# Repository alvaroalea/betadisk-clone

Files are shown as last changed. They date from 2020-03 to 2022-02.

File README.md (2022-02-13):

# The Beta 128K Interface Disk for ZX Spectrum
the schematic and PCB for this interfaz, make in KICAD
Including gerber files to direct order, the PCB is just 15x10cm.

# THIS IS WORK IN PROGRESS.ACTUALY THIS INTERFACE DO NOT WORK!!!!! BE AWARE
## NOT FOR USE, THIS IS ONLY A MOCKUP, WORK IN PROGRESS

(C) 2018 Alvaro Alea Fernandez.



This work is licensed under a Creative Commons Attribution-NonCommercial-ShareAlike 4.0 International License.

http://creativecommons.org/licenses/by-nc-sa/4.0/

BOM is probably not acurrate, gerbers have names wrong.

GAL code is not checked

Even this interface provide a back conector for other interfaces, it do not provide a good IORQ signals, so can be incompatible with other interfaces that original interface is working good.

This board hide the serial port on +2.

The Advantege of this interfaz over the original are:

- 4 Banks of ROM, so you can swap between diferent versiones of TR-Dos. selectable by dip-switches
  (TR-DOS 5.03 and 5.04T with fixed, TR-DOS 6.04 & velesoft 5.03 with monitor.

- Posibility of use crossed and plain floppy cable, and invert Drive 1 and Drive 2, very usefull if you have a Gotek and a real floppy.

- Jumper for swap D0 & D7 (because some roms are distributed with this bits swapeed)

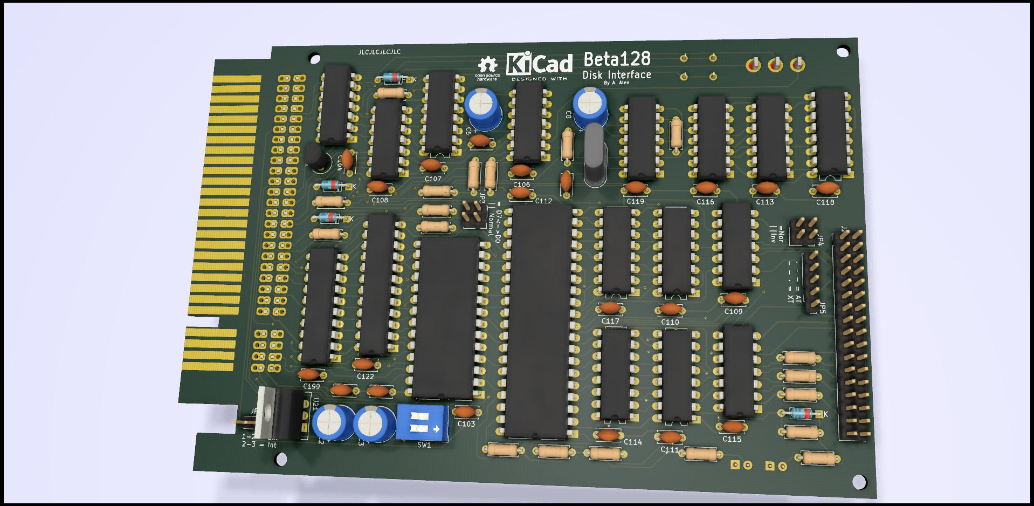
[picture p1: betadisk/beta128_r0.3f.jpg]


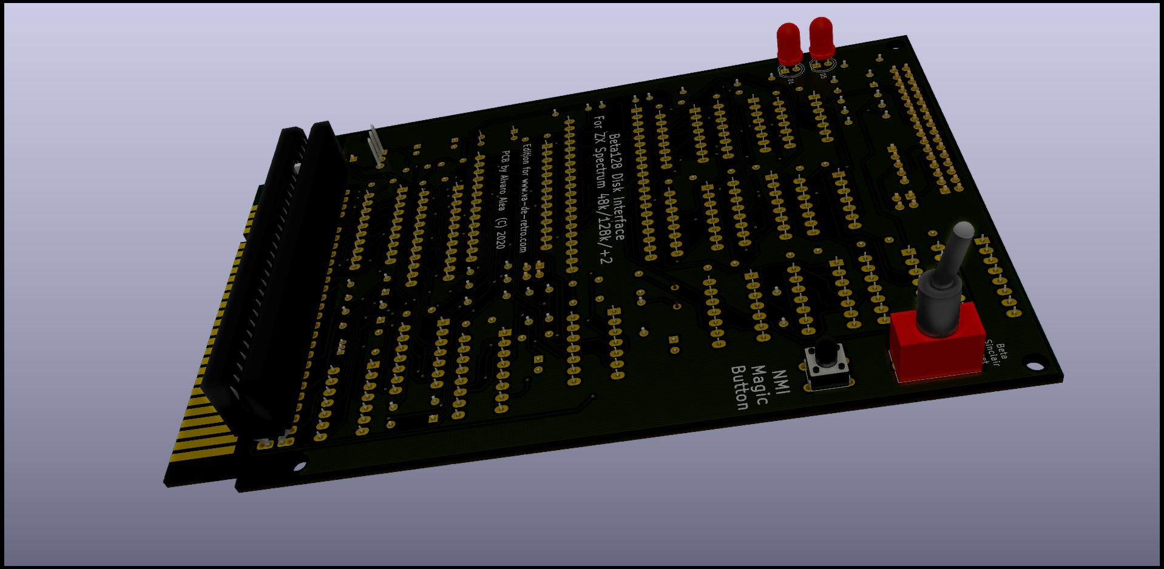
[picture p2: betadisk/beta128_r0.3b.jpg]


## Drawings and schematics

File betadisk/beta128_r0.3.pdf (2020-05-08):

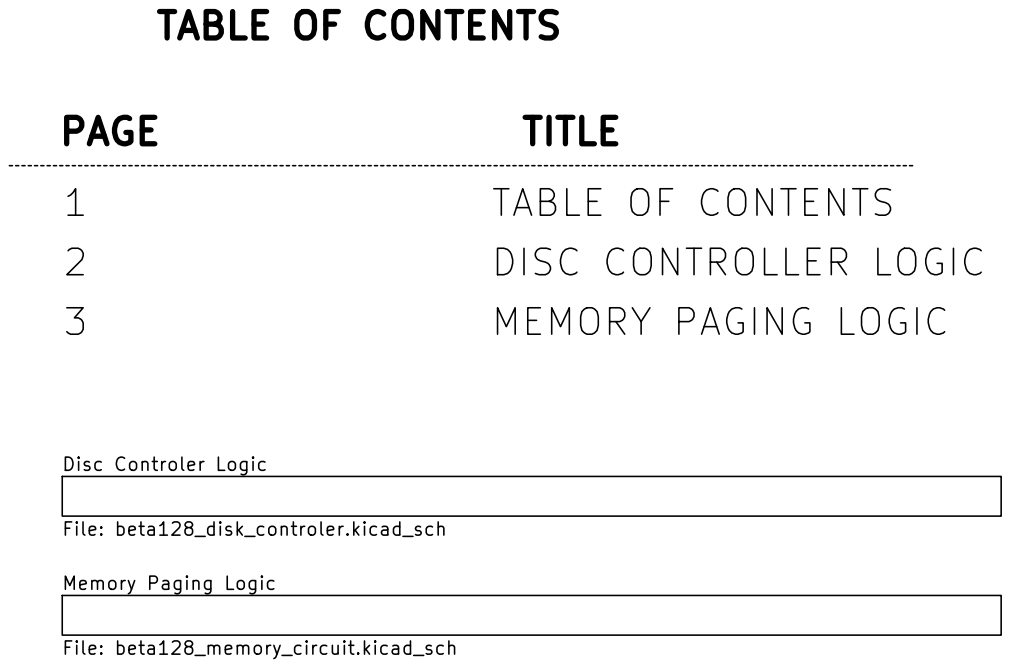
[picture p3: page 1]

Disc Controler Logic File: beta128_disk_controler.kicad_sch Memory Paging Logic

File: beta128_r0.3.kicad_sch Sheet: / Alvaro Alea Fdz. Based on Rev 5 (Beta 128) Under Licence GPL3

Id: 1/3 Title: Beta Disk Interface

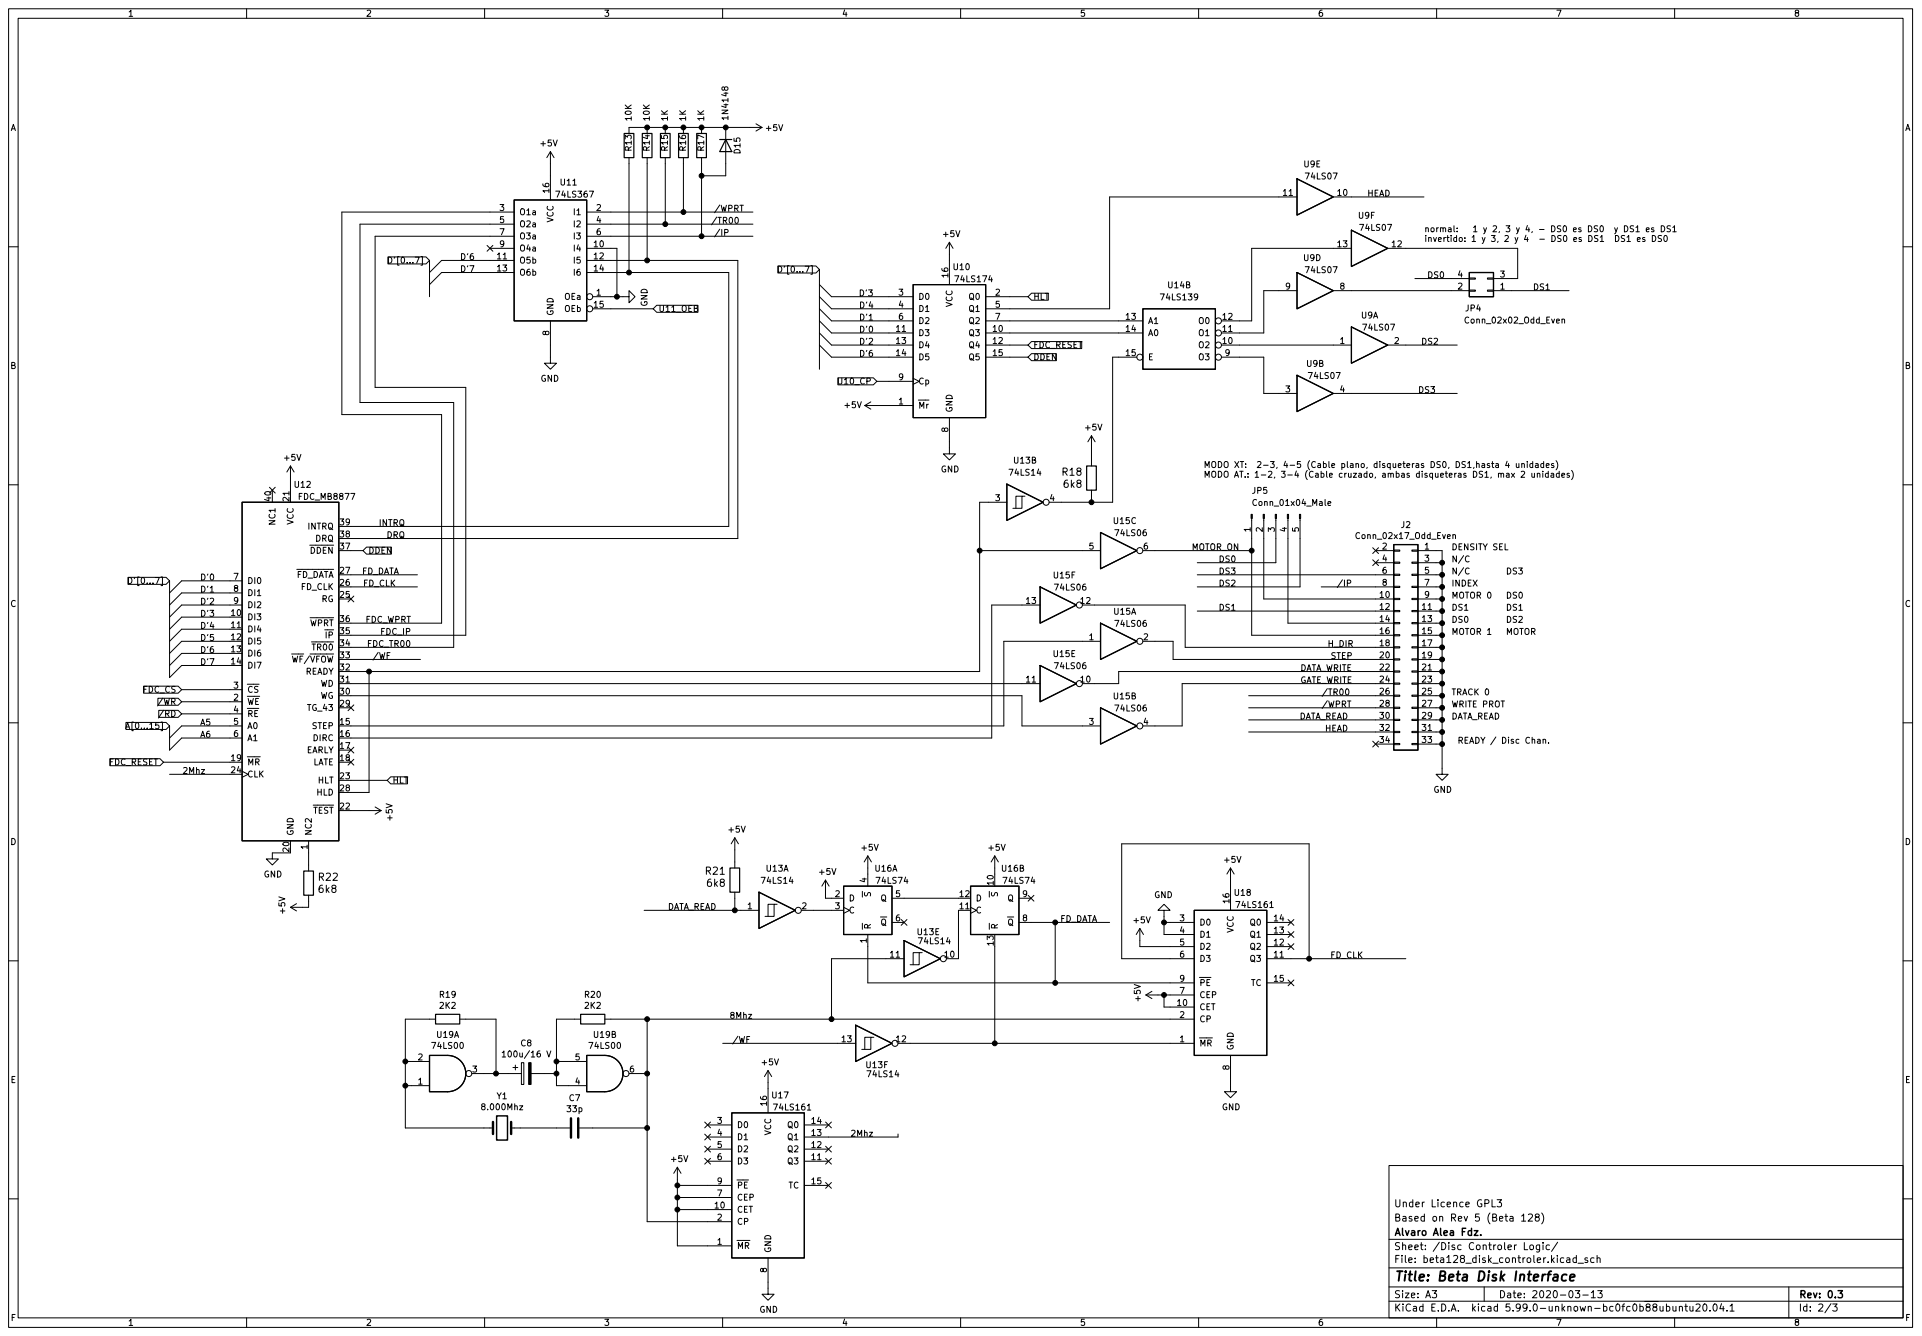
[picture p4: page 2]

invertido: 1 y 3, 2 y 4 - DS0 es DS1 DS1 es DS0 DENSITY SEL TRACK 0 WRITE PROT DATA_READ

24 | 23
26 | 25

File: beta128_disk_controler.kicad_sch
Id: 2/3 Title: Beta Disk Interface

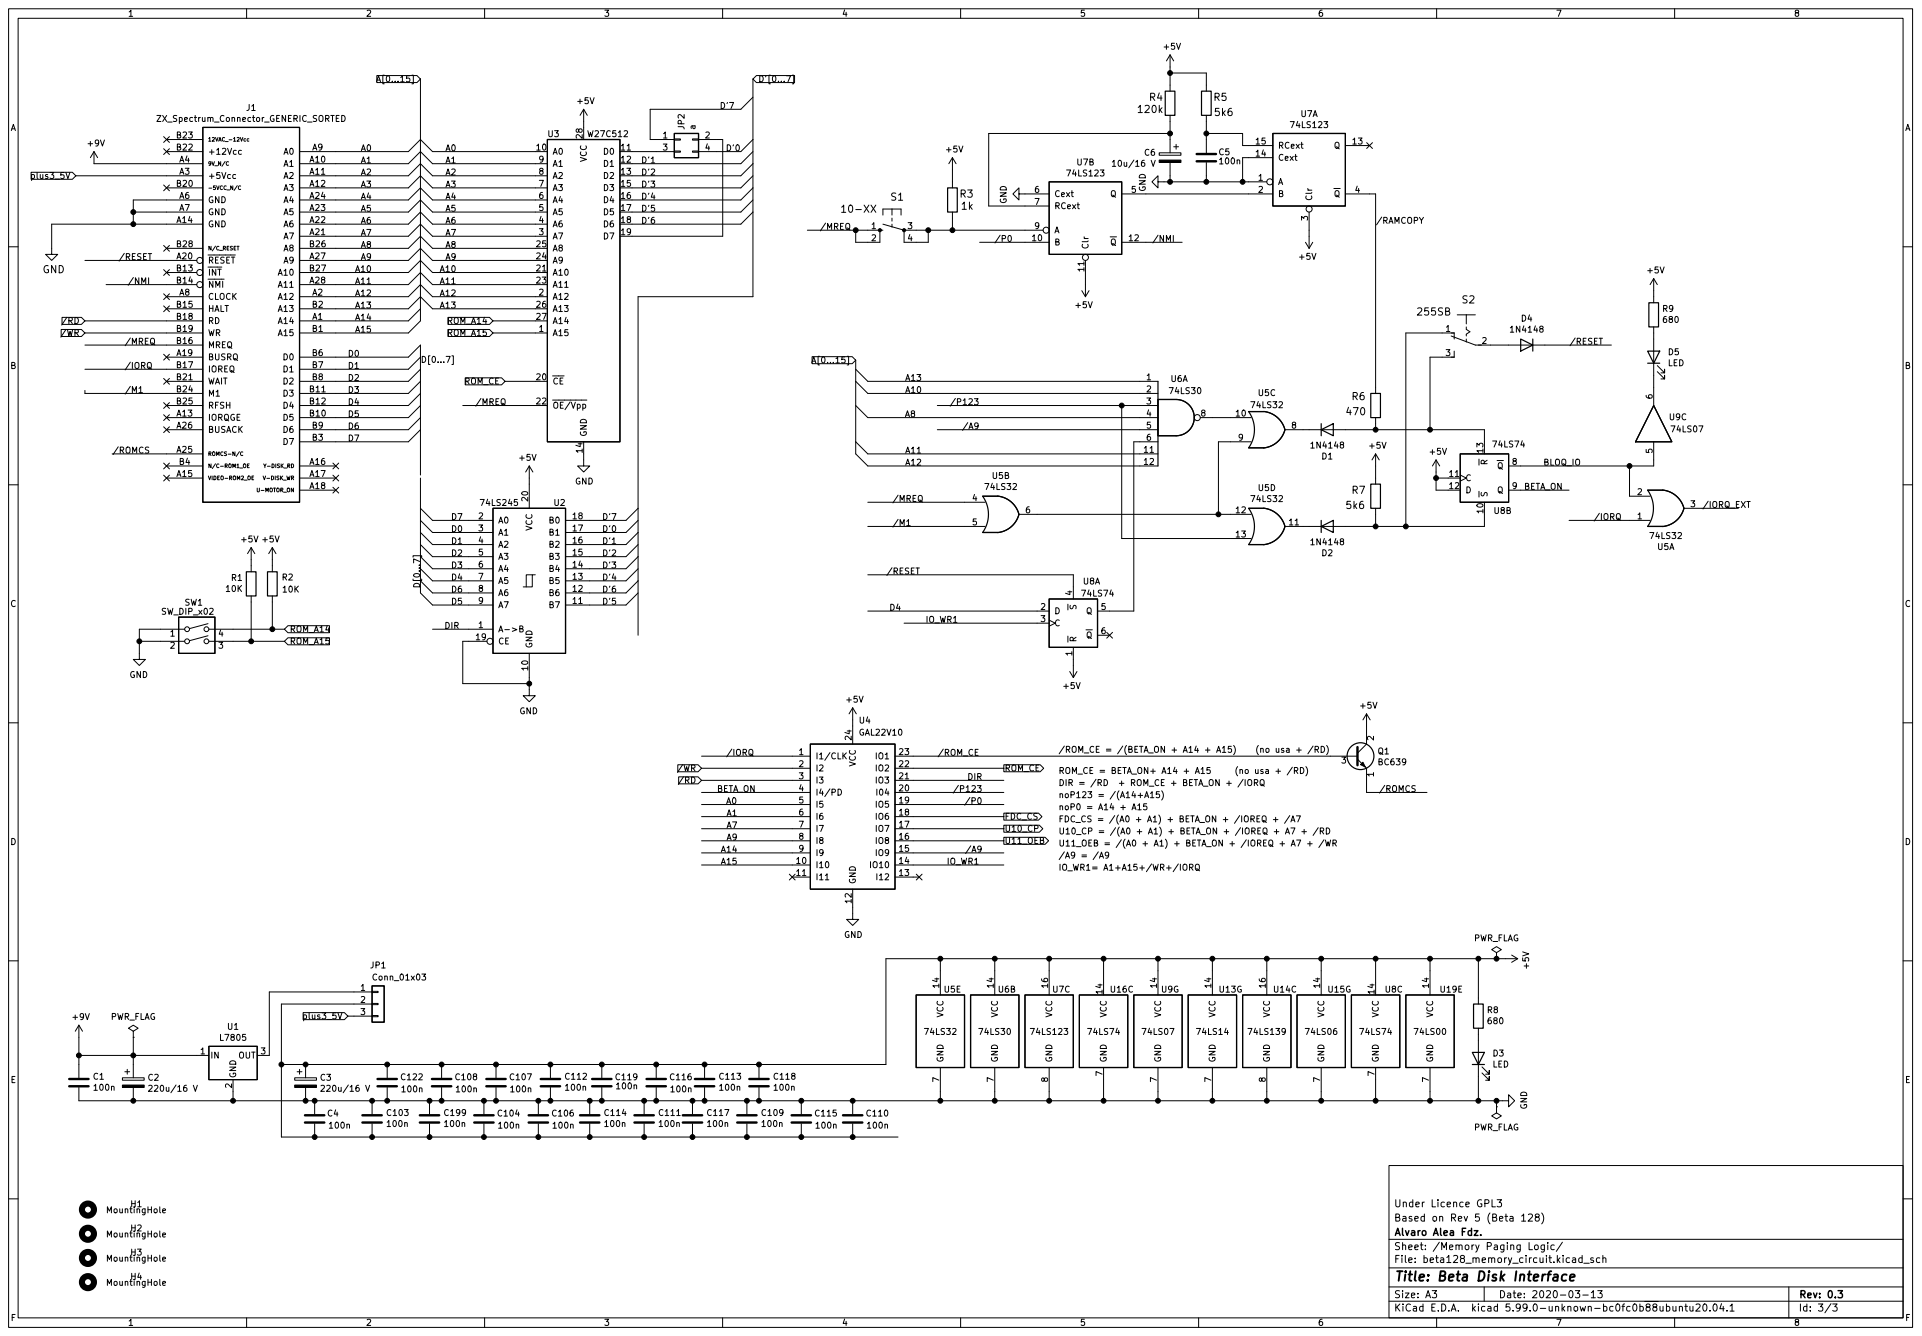
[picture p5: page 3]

Sheet: /Memory Paging Logic/ Alvaro Alea Fdz. Based on Rev 5 (Beta 128) Under Licence GPL3

File: beta128_memory_circuit.kicad_sch
Id: 3/3 Title: Beta Disk Interface

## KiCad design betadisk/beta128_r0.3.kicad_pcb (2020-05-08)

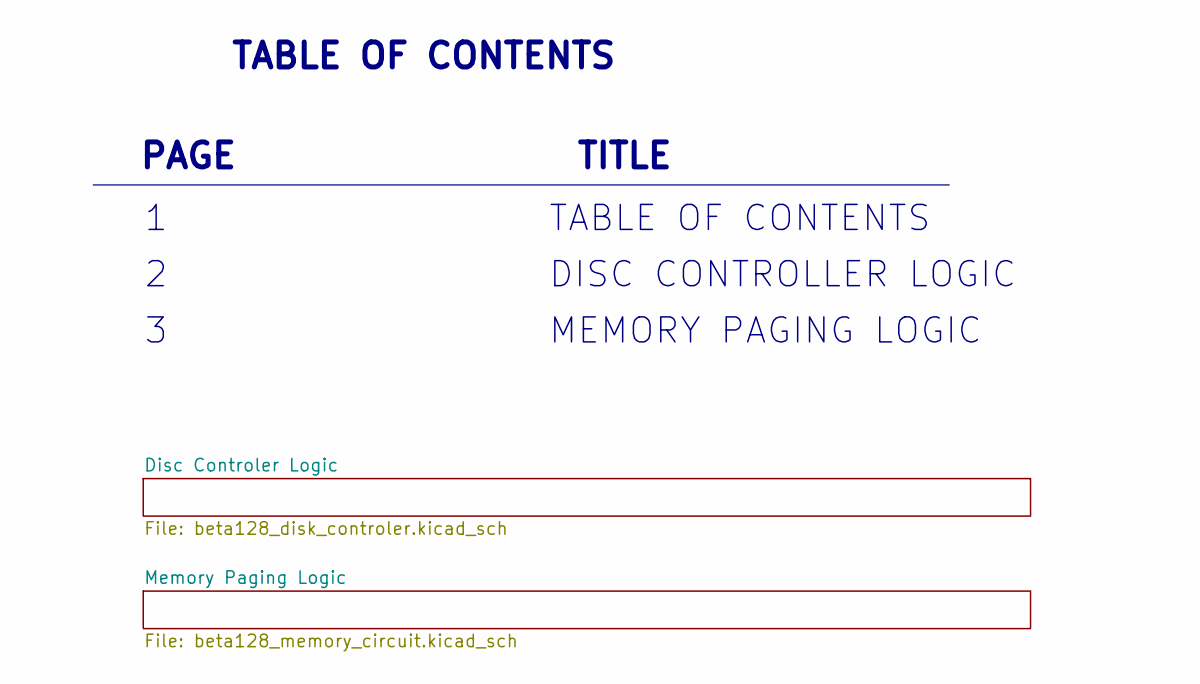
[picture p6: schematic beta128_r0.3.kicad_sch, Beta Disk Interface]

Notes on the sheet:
1 TABLE OF CONTENTS
2 DISC CONTROLLER LOGIC
3 MEMORY PAGING LOGIC
TABLE OF CONTENTS
PAGE TITLE

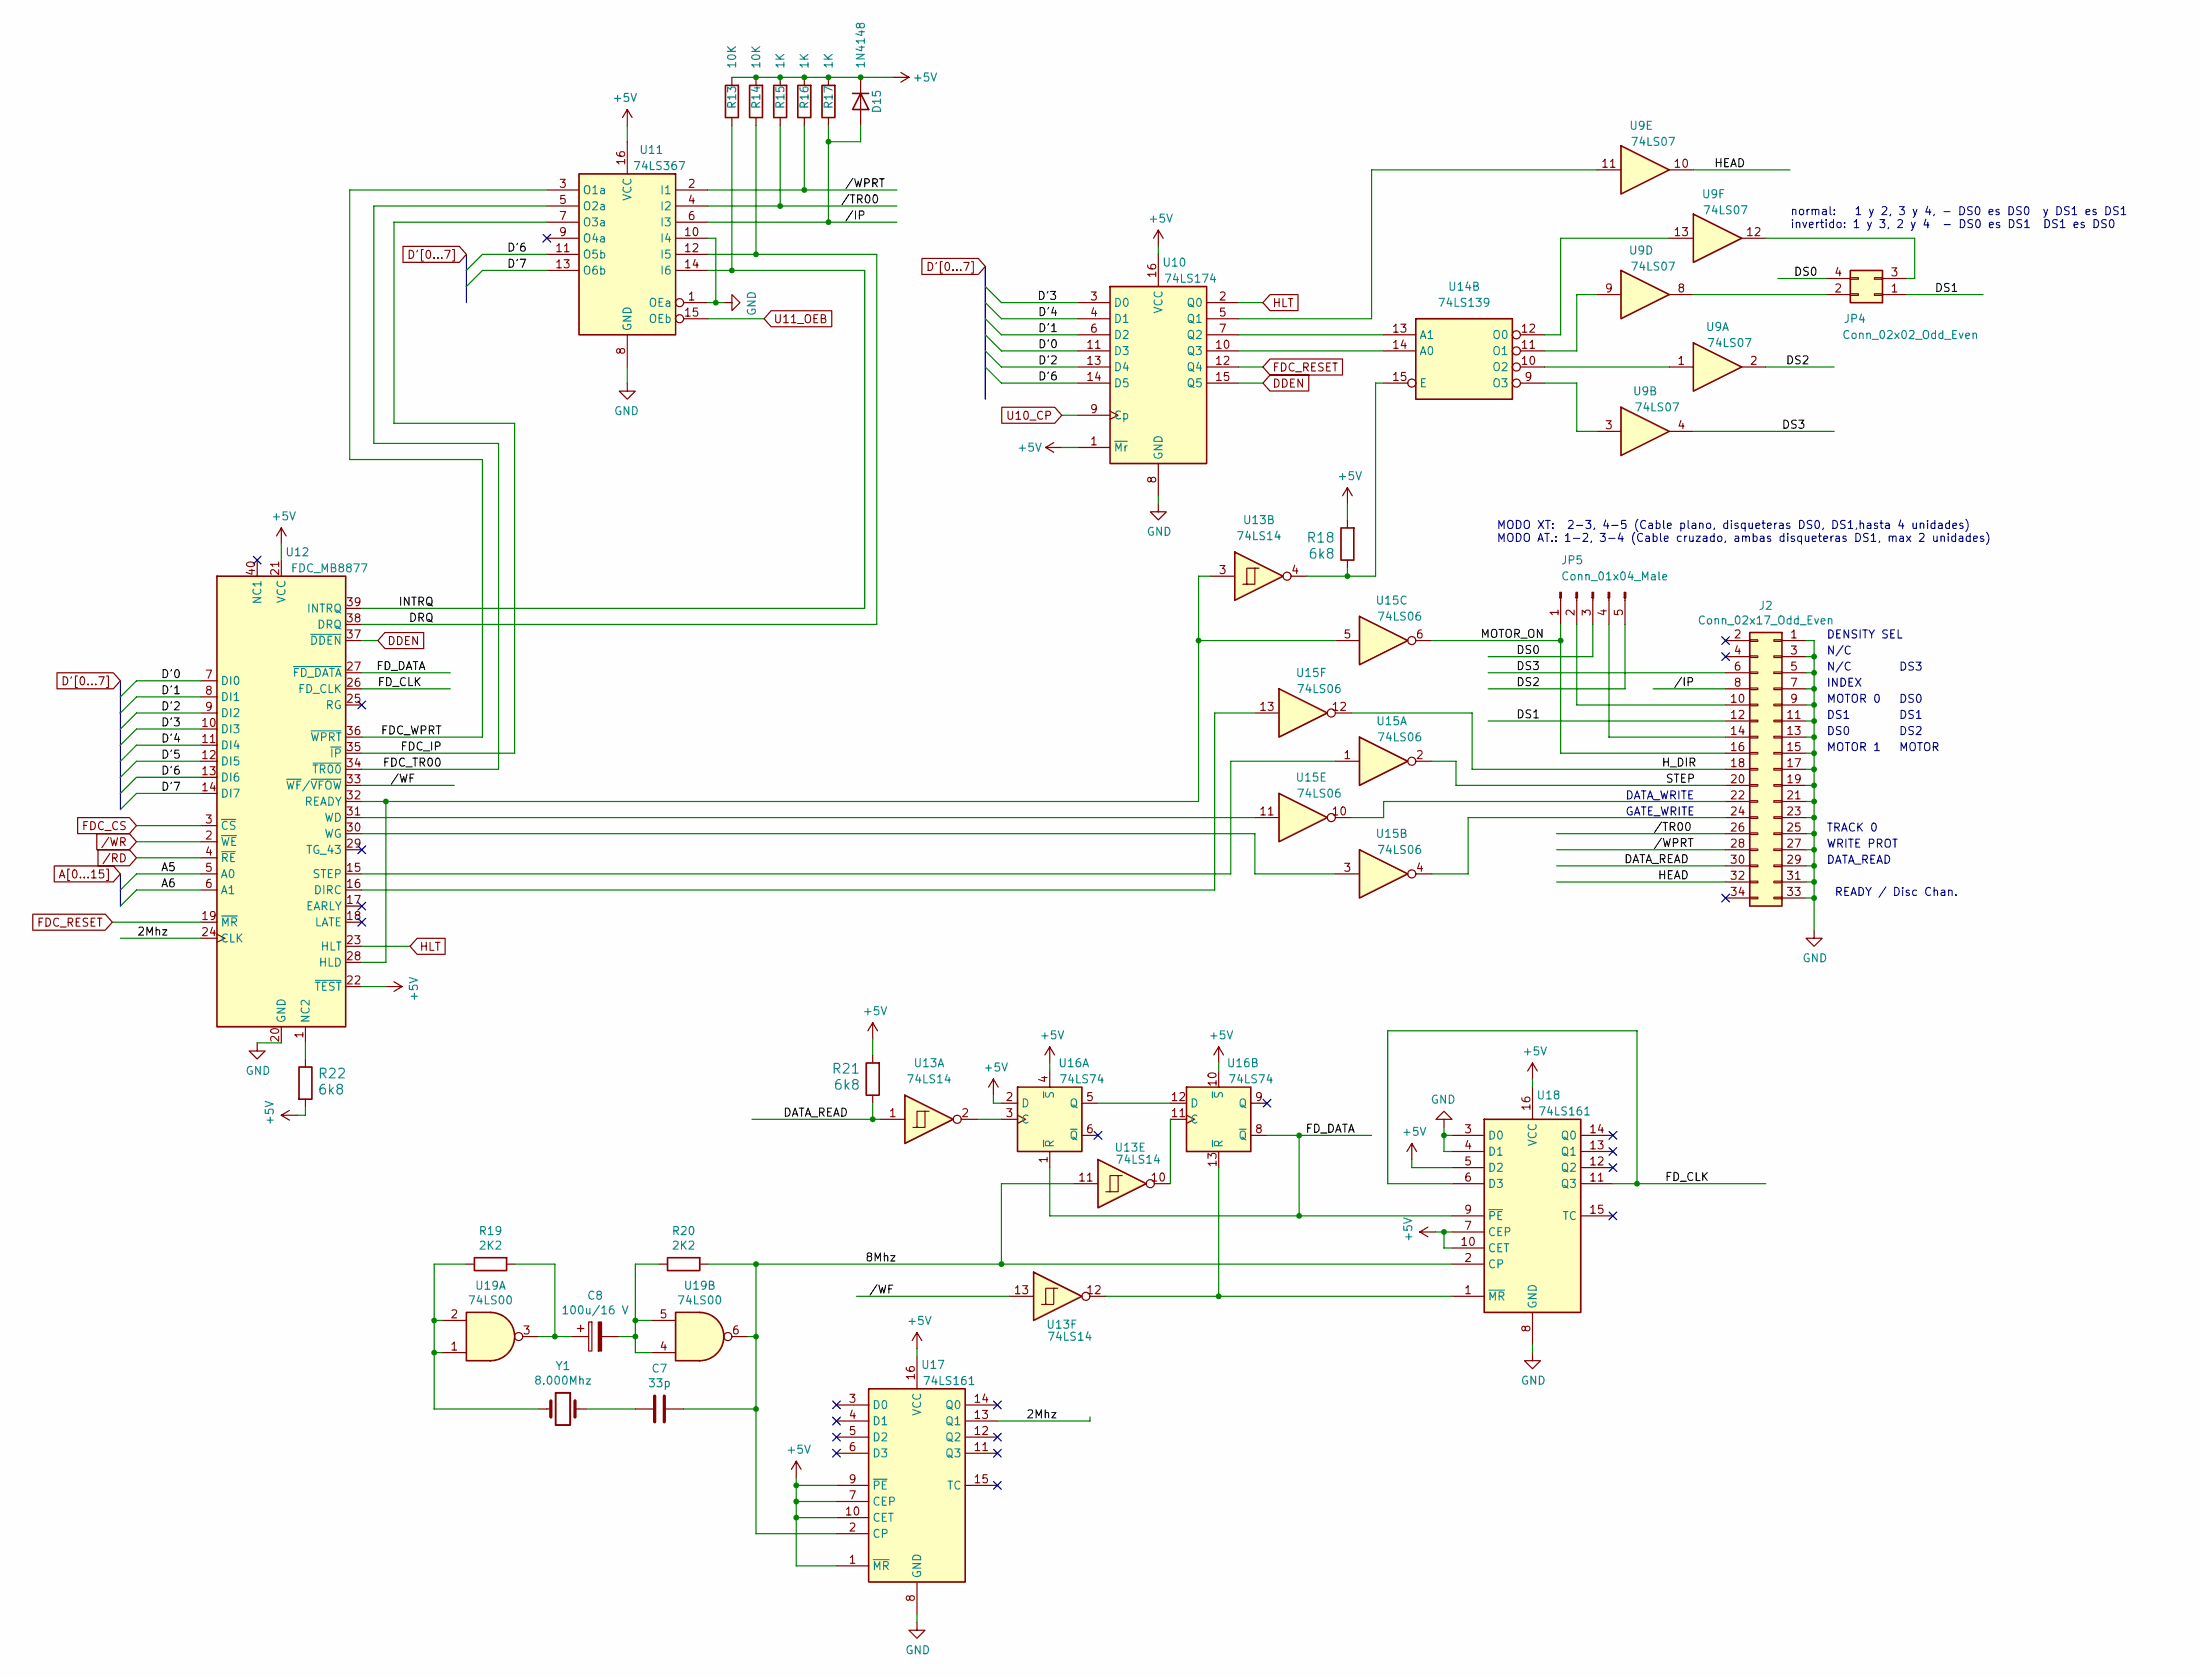
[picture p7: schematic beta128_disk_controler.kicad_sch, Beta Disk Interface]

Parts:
C7: 33p; C_Disc_D5.0mm_W2.5mm_P5.00mm
C8: 100u/16 V; CP_Radial_D7.5mm_P2.50mm
D15: 1N4148; D_DO-35_SOD27_P7.62mm_Horizontal
J2: Conn_02x17_Odd_Even; PinHeader_2x17_P2.54mm_Vertical
JP4: Conn_02x02_Odd_Even; PinHeader_2x02_P2.54mm_Vertical
JP5: Conn_01x04_Male; PinHeader_1x05_P2.54mm_Vertical
R13, R14: 10K; R_Axial_DIN0207_L6.3mm_D2.5mm_P7.62mm_Horizontal
R15, R16, R17: 1K; R_Axial_DIN0207_L6.3mm_D2.5mm_P7.62mm_Horizontal
R18, R21, R22: 6k8; R_Axial_DIN0207_L6.3mm_D2.5mm_P7.62mm_Horizontal
R19, R20: 2K2; R_Axial_DIN0207_L6.3mm_D2.5mm_P7.62mm_Horizontal
U9: 74LS07; DIP-14_W7.62mm_LongPads
U10: 74LS174; DIP-16_W7.62mm_LongPads
U11: 74LS367; DIP-16_W7.62mm_LongPads
U12: FDC_MB8877; DIP-40_W15.24mm_LongPads
U13: 74LS14; DIP-14_W7.62mm_LongPads
U14: 74LS139; DIP-16_W7.62mm_LongPads
U15: 74LS06; DIP-14_W7.62mm_LongPads
U16: 74LS74; DIP-14_W7.62mm_LongPads
U17, U18: 74LS161; DIP-16_W7.62mm_LongPads
U19: 74LS00; DIP-14_W7.62mm_LongPads
Y1: 8.000Mhz; Crystal_HC18-U_Vertical

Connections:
+5V: D15.1 (K), R13.2, R14.2, R15.2, R16.2, R17.2, R18.2, R21.2, R22.2, U10.1 (~Mr), U10.16 (VCC), U11.16 (VCC), U12.21 (VCC), U12.22 (~TEST), U16.2 (D), U16.4 (~S), U16.10 (~S), U17.1 (~MR), U17.7 (CEP), U17.9 (~PE), U17.10 (CET), U17.16 (VCC), U18.5 (D2), U18.7 (CEP), U18.10 (CET), U18.16 (VCC); also elsewhere on the board
/Disc Controler Logic/2Mhz: U12.24 (CLK), U17.13 (Q1)
/Disc Controler Logic/8Mhz: C7.2, R20.2, U13.11, U17.2 (CP), U18.2 (CP), U19.6
/Disc Controler Logic//IP: D15.2 (A), J2.8, R17.1, U11.6 (I3)
/Disc Controler Logic//TR00: J2.26, R15.1, U11.4 (I2)
/Disc Controler Logic//WF: U12.33 (~WF~/~VFOW), U13.13
/Disc Controler Logic//WPRT: J2.28, R16.1, U11.2 (I1)
/Disc Controler Logic/DATA_READ: J2.30, R21.1, U13.1
/Disc Controler Logic/DRQ: R14.1, U11.12 (I5), U12.38 (DRQ)
/Disc Controler Logic/DS0: JP4.4, JP5.3
/Disc Controler Logic/DS1: J2.12, JP4.1
/Disc Controler Logic/DS2: JP5.5, U9.2
/Disc Controler Logic/DS3: J2.6, U9.4
/Disc Controler Logic/FDC_IP: U11.7 (O3a), U12.35 (~IP)
/Disc Controler Logic/FDC_TR00: U11.5 (O2a), U12.34 (~TR00)
/Disc Controler Logic/FDC_WPRT: U11.3 (O1a), U12.36 (~WPRT)
/Disc Controler Logic/FD_CLK: U12.26 (FD_CLK), U18.6 (D3), U18.11 (Q3)
/Disc Controler Logic/FD_DATA: U12.27 (~FD_DATA), U16.1 (~R), U16.8 (~Q), U18.9 (~PE)
/Disc Controler Logic/HEAD: J2.32, U9.10
/Disc Controler Logic/H_DIR: J2.18, U15.12
/Disc Controler Logic/INTRQ: R13.1, U11.14 (I6), U12.39 (INTRQ)
/Disc Controler Logic/MOTOR_ON: J2.16, JP5.1, U15.6
/Disc Controler Logic/STEP: J2.20, U15.2
/RD: U12.4 (~RE); also elsewhere on the board
/WR: U12.2 (~WE); also elsewhere on the board
A5: U12.5 (A0); also elsewhere on the board
A6: U12.6 (A1); also elsewhere on the board
D'0: U10.11 (D3), U12.7 (DI0); also elsewhere on the board
D'1: U10.6 (D2), U12.8 (DI1); also elsewhere on the board
D'2: U10.13 (D4), U12.9 (DI2); also elsewhere on the board
D'3: U10.3 (D0), U12.10 (DI3); also elsewhere on the board
D'4: U10.4 (D1), U12.11 (DI4); also elsewhere on the board
D'5: U12.12 (DI5); also elsewhere on the board
D'6: U10.14 (D5), U11.11 (O5b), U12.13 (DI6); also elsewhere on the board
D'7: U11.13 (O6b), U12.14 (DI7); also elsewhere on the board
DDEN: U10.15 (Q5), U12.37 (~DDEN)
FDC_CS: U12.3 (~CS); also elsewhere on the board
FDC_RESET: U10.12 (Q4), U12.19 (~MR)
GND: J2.1, J2.3, J2.5, J2.7, J2.9, J2.11, J2.13, J2.15, J2.17, J2.19, J2.21, J2.23, J2.25, J2.27, J2.29, J2.31, J2.33, U10.8 (GND), U11.1 (OEa), U11.8 (GND), U11.10 (I4), U12.20 (GND), U17.8 (GND), U18.3 (D0), U18.4 (D1), U18.8 (GND); also elsewhere on the board
HLT: U10.2 (Q0), U12.23 (HLT)
unnamed: C7.1, Y1.1
unnamed: C8.1, R19.2, U19.3
unnamed: C8.2, R20.1, U19.4, U19.5
unnamed: J2.10, JP5.2
unnamed: J2.14, JP5.4
unnamed: J2.22, U15.10
unnamed: J2.24, U15.4
unnamed: JP4.2, U9.8
unnamed: JP4.3, U9.12
unnamed: R18.1, U13.4, U14.15 (E)
unnamed: R19.1, U19.1, U19.2, Y1.2
unnamed: R22.1, U12.1 (NC2)
unnamed: U9.11, U10.5 (Q1)
unnamed: U10.7 (Q2), U14.13 (A1)
unnamed: U10.10 (Q3), U14.14 (A0)
unnamed: U12.15 (STEP), U15.1
unnamed: U12.16 (DIRC), U15.13
unnamed: U12.28 (HLD), U12.32 (READY), U13.3, U15.5
unnamed: U12.30 (WG), U15.3
unnamed: U12.31 (WD), U15.11
unnamed: U13.2, U16.3 (C)
unnamed: U13.10, U16.11 (C)
unnamed: U13.12, U16.13 (~R), U18.1 (~MR)
unnamed: U9.3, U14.9 (O3)
unnamed: U9.1, U14.10 (O2)
unnamed: U9.9, U14.11 (O1)
unnamed: U9.13, U14.12 (O0)
unnamed: U16.5 (Q), U16.12 (D)
U10_CP: U10.9 (Cp); also elsewhere on the board
U11_OEB: U11.15 (OEb); also elsewhere on the board

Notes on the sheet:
MODO XT: 2-3, 4-5 (Cable plano, disqueteras DS0, DS1,hasta 4 unidades) MODO AT.: 1-2, 3-4 (Cable cruzado, ambas disqueteras DS1, max 2 unidades)
DATA_WRITE
GATE_WRITE
normal: 1 y 2, 3 y 4, - DS0 es DS0 y DS1 es DS1 invertido: 1 y 3, 2 y 4 - DS0 es DS1 DS1 es DS0
DENSITY SEL
N/C
INDEX
MOTOR 0
DS1
DS0
MOTOR 1
TRACK 0
WRITE PROT
DATA_READ
READY / Disc Chan.
DS3
DS0
DS2
MOTOR

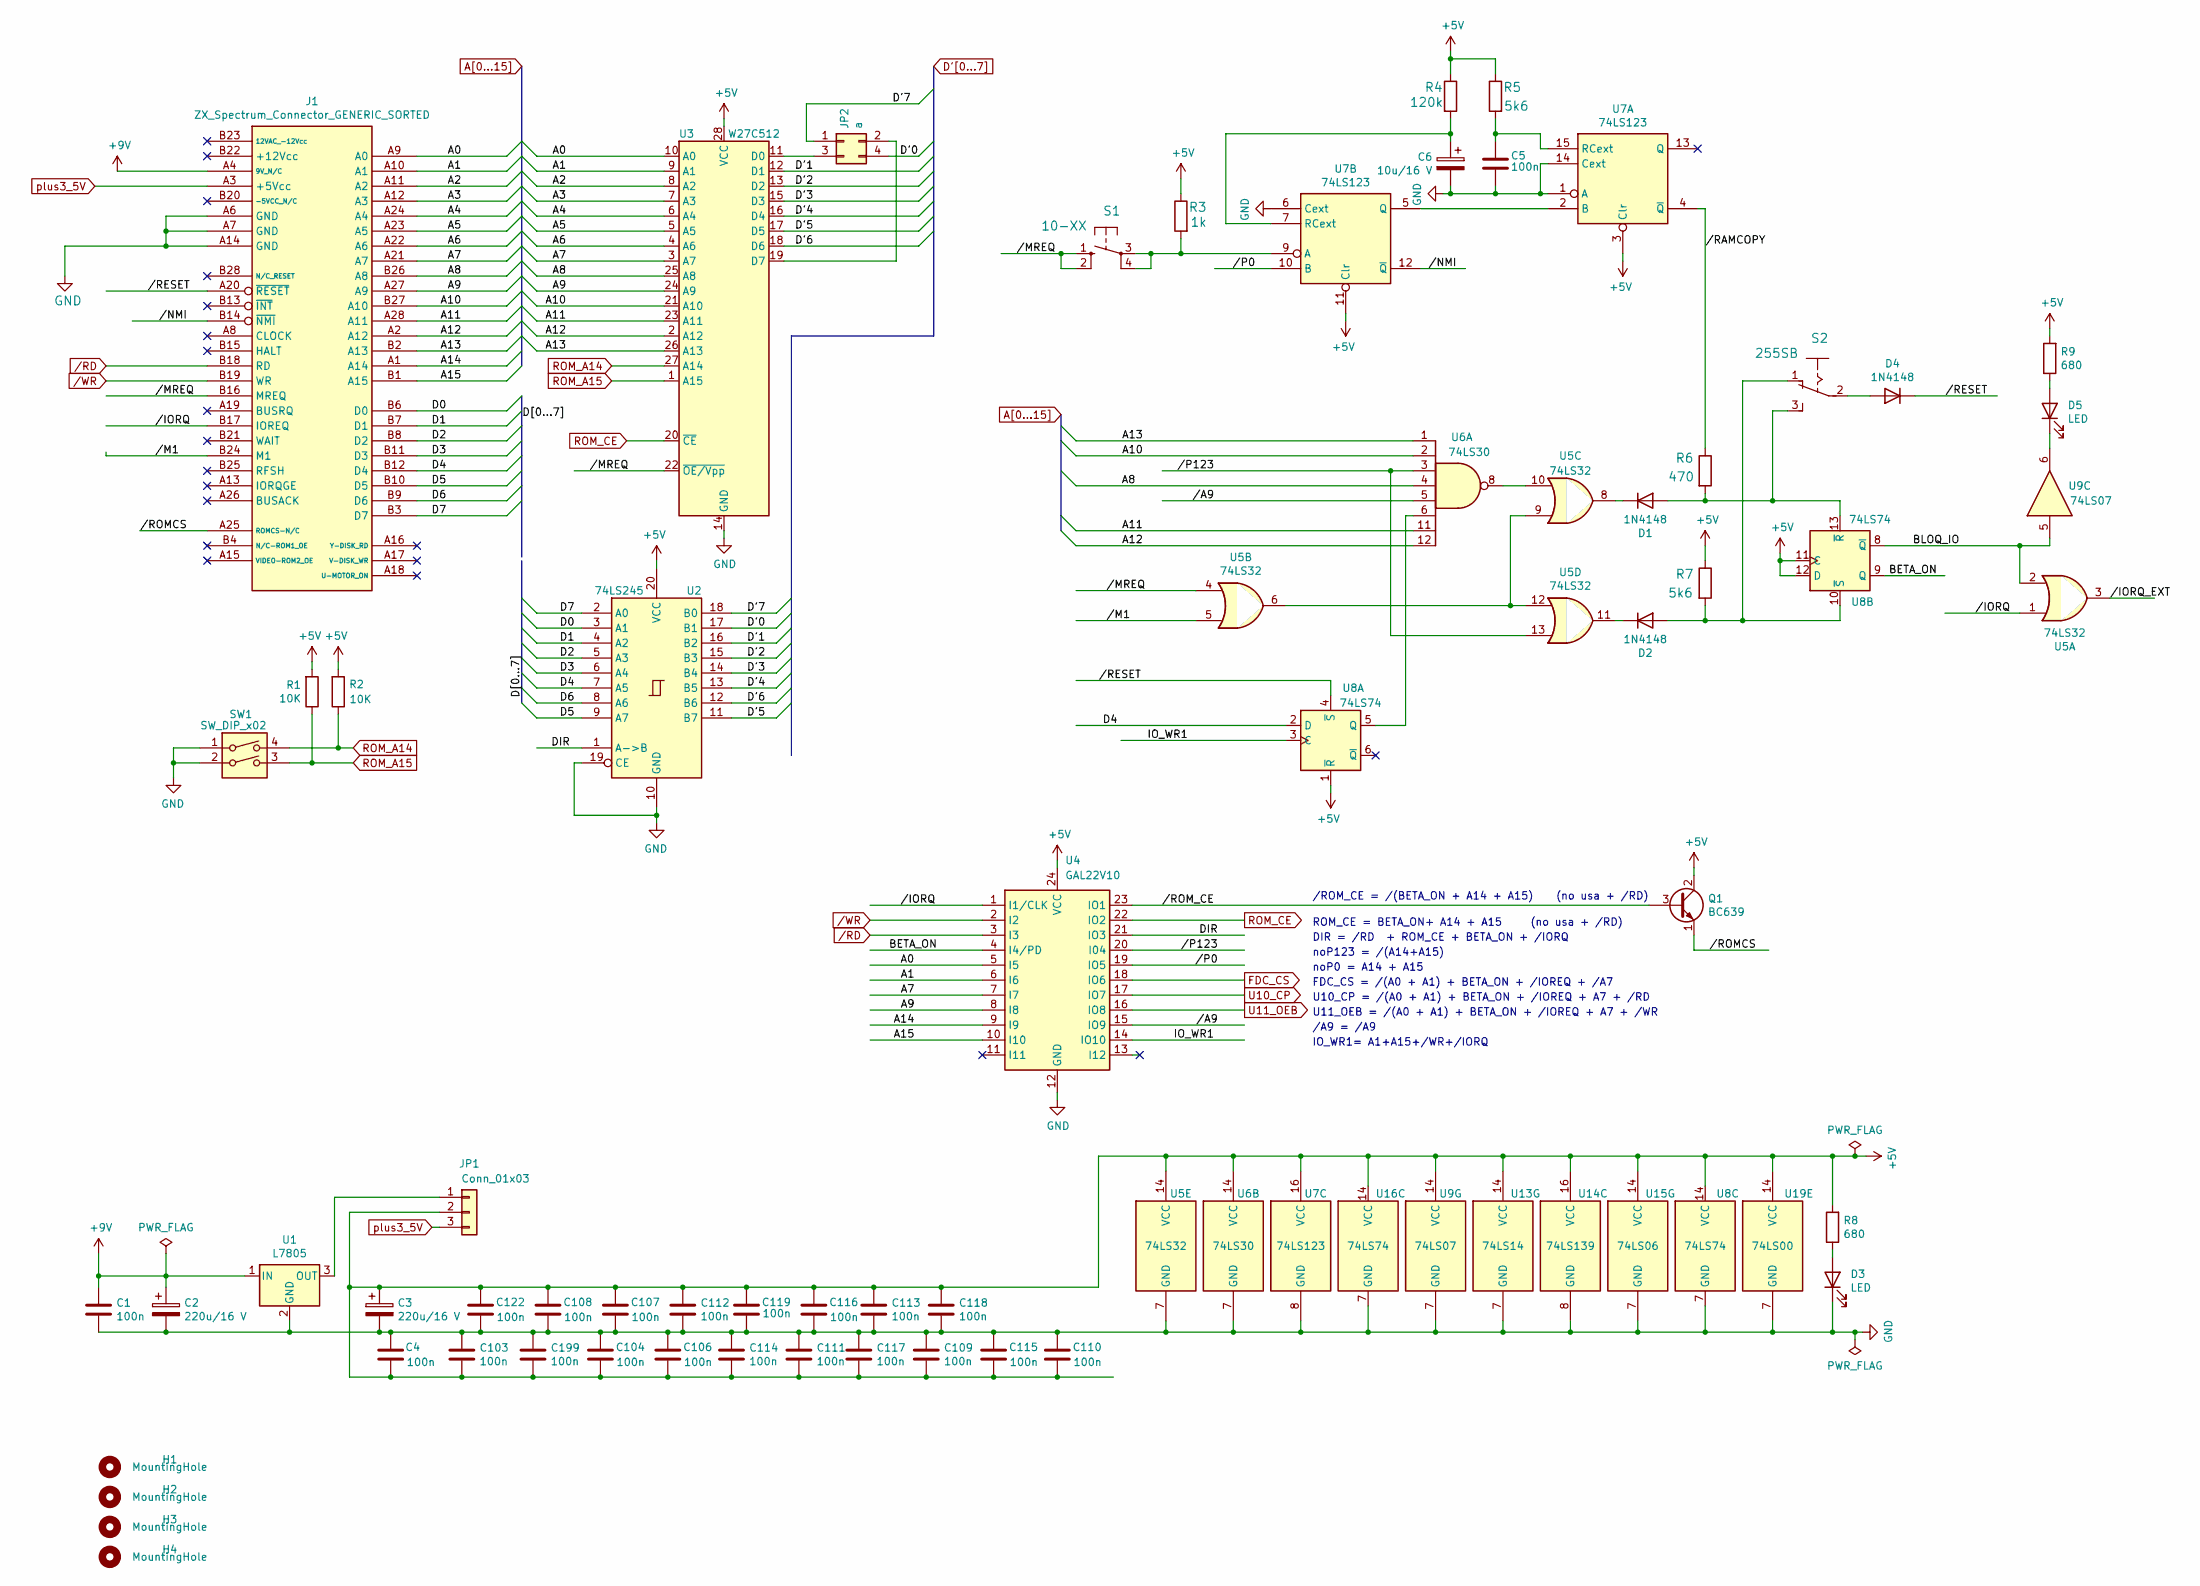
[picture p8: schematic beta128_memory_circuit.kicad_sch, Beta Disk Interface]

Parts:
C1, C4, C5, C103, C104, C106, C107, C108, C109, C110, C111, C112, C113, C114, C115, C116, C117, C118, C119, C122, C199: 100n; C_Disc_D5.0mm_W2.5mm_P5.00mm
C2, C3: 220u/16 V; CP_Radial_D7.5mm_P2.50mm
C6: 10u/16 V; CP_Radial_D7.5mm_P2.50mm
D1, D2, D4: 1N4148; D_DO-35_SOD27_P7.62mm_Horizontal
D3, D5: LED; LED_D5.0mm
H1, H2, H3, H4: MountingHole; MountingHole_3mm
J1: ZX_Spectrum_Connector_GENERIC_SORTED; ZX_EDGE_90extend
JP1: Conn_01x03; PinHeader_1x03_P2.54mm_Vertical
JP2: a; PinHeader_2x02_P2.54mm_Vertical
Q1: BC639; TO-92_Inline
R1, R2: 10K; R_Axial_DIN0207_L6.3mm_D2.5mm_P7.62mm_Horizontal
R3: 1k; R_Axial_DIN0207_L6.3mm_D2.5mm_P7.62mm_Horizontal
R4: 120k; R_Axial_DIN0207_L6.3mm_D2.5mm_P7.62mm_Horizontal
R5, R7: 5k6; R_Axial_DIN0207_L6.3mm_D2.5mm_P7.62mm_Horizontal
R6: 470; R_Axial_DIN0207_L6.3mm_D2.5mm_P7.62mm_Horizontal
R8, R9: 680; R_Axial_DIN0207_L6.3mm_D2.5mm_P7.62mm_Horizontal
S1: 10-XX; SW_TH_Tactile_Omron_B3F-10xx
S2: 255SB; SW_C&K_710x-xx-xx-Z-_SPDT
SW1: SW_DIP_x02; SW_DIP_SPSTx02_Slide_9.78x7.26mm_W7.62mm_P2.54mm
U1: L7805; TO-220-3_Vertical
U2: 74LS245; DIP-20_W7.62mm_LongPads
U3: W27C512; DIP-28_W15.24mm_LongPads
U4: GAL22V10; DIP-24_W7.62mm_LongPads
U5: 74LS32; DIP-14_W7.62mm_LongPads
U6: 74LS30; DIP-14_W7.62mm_LongPads
U7: 74LS123; DIP-16_W7.62mm_LongPads
U8, U16: 74LS74; DIP-14_W7.62mm_LongPads
U9: 74LS07; DIP-14_W7.62mm_LongPads
U13: 74LS14; DIP-14_W7.62mm_LongPads
U14: 74LS139; DIP-16_W7.62mm_LongPads
U15: 74LS06; DIP-14_W7.62mm_LongPads
U19: 74LS00; DIP-14_W7.62mm_LongPads

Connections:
+5V: C3.1, C4.2, C103.1, C104.2, C106.2, C107.1, C108.1, C109.1, C110.2, C111.1, C112.2, C113.2, C114.1, C115.2, C116.1, C117.1, C118.2, C119.1, C122.1, C199.1, JP1.2, Q1.2 (C), R1.2, R2.2, R3.1, R4.1, R5.1, R7.1, R8.2, R9.2, U2.20 (VCC), U3.28 (VCC), U4.24 (VCC), U5.14 (VCC), U6.14 (VCC), U7.3 (Clr), U7.11 (Clr), U7.16 (VCC), U8.1 (~R), U8.11 (C), U8.12 (D), U8.14 (VCC), U9.14 (VCC), U13.14 (VCC), U14.16 (VCC), U15.14 (VCC), U16.14 (VCC), U19.14 (VCC); also elsewhere on the board
+9V: C1.2, C2.1, J1.A4 (9V_N/C), U1.1 (IN)
/Memory Paging Logic//A9: U4.15 (IO9), U6.5
/Memory Paging Logic//IORQ: J1.B17 (IOREQ), U4.1 (I1/CLK), U5.1
/Memory Paging Logic//M1: J1.B24 (M1), U5.5
/Memory Paging Logic//MREQ: J1.B16 (MREQ), S1.1 (S), S1.2 (S1), U3.22 (~OE/Vpp), U5.4
/Memory Paging Logic//NMI: J1.B14 (~NMI), U7.12 (~Q)
/Memory Paging Logic//P0: U4.19 (IO5), U7.10 (B)
/Memory Paging Logic//P123: U4.20 (I04), U5.13, U6.3
/Memory Paging Logic//RAMCOPY: R6.1, U7.4 (~Q)
/Memory Paging Logic//RESET: D4.1 (K), J1.A20 (~RESET), U8.4 (~S)
/Memory Paging Logic//ROMCS: J1.A25 (ROMCS-N/C), Q1.1 (E)
/Memory Paging Logic//ROM_CE: Q1.3 (B), U4.23 (IO1)
/Memory Paging Logic/BETA_ON: U4.4 (I4/PD), U8.9 (Q)
/Memory Paging Logic/BLOQ_IO: U5.2, U8.8 (~Q), U9.5
/Memory Paging Logic/D0: J1.B6 (D0), U2.3 (A1)
/Memory Paging Logic/D1: J1.B7 (D1), U2.4 (A2)
/Memory Paging Logic/D2: J1.B8 (D2), U2.5 (A3)
/Memory Paging Logic/D3: J1.B11 (D3), U2.6 (A4)
/Memory Paging Logic/D4: J1.B12 (D4), U2.7 (A5), U8.2 (D)
/Memory Paging Logic/D5: J1.B10 (D5), U2.9 (A7)
/Memory Paging Logic/D6: J1.B9 (D6), U2.8 (A6)
/Memory Paging Logic/D7: J1.B3 (D7), U2.2 (A0)
/Memory Paging Logic/DIR: U2.1 (A->B), U4.21 (IO3)
/Memory Paging Logic/IO_WR1: U4.14 (IO10), U8.3 (C)
/RD: J1.B18 (RD), U4.3 (I3); also elsewhere on the board
/WR: J1.B19 (WR), U4.2 (I2); also elsewhere on the board
A0: J1.A9 (A0), U3.10 (A0), U4.5 (I5)
A1: J1.A10 (A1), U3.9 (A1), U4.6 (I6)
A2: J1.A11 (A2), U3.8 (A2)
A3: J1.A12 (A3), U3.7 (A3)
A4: J1.A24 (A4), U3.6 (A4)
A5: J1.A23 (A5), U3.5 (A5); also elsewhere on the board
A6: J1.A22 (A6), U3.4 (A6); also elsewhere on the board
A7: J1.A21 (A7), U3.3 (A7), U4.7 (I7)
A8: J1.B26 (A8), U3.25 (A8), U6.4
A9: J1.A27 (A9), U3.24 (A9), U4.8 (I8)
A10: J1.B27 (A10), U3.21 (A10), U6.2
A11: J1.A28 (A11), U3.23 (A11), U6.11
A12: J1.A2 (A12), U3.2 (A12), U6.12
A13: J1.B2 (A13), U3.26 (A13), U6.1
A14: J1.A1 (A14), U4.9 (I9)
A15: J1.B1 (A15), U4.10 (I10)
D'0: JP2.4, U2.17 (B1); also elsewhere on the board
D'1: U2.16 (B2), U3.12 (D1); also elsewhere on the board
D'2: U2.15 (B3), U3.13 (D2); also elsewhere on the board
D'3: U2.14 (B4), U3.15 (D3); also elsewhere on the board
D'4: U2.13 (B5), U3.16 (D4); also elsewhere on the board
D'5: U2.11 (B7), U3.17 (D5); also elsewhere on the board
D'6: U2.12 (B6), U3.18 (D6); also elsewhere on the board
D'7: JP2.1, U2.18 (B0); also elsewhere on the board
FDC_CS: U4.18 (IO6); also elsewhere on the board
GND: C1.1, C2.2, C3.2, C4.1, C5.2, C6.2, C103.2, C104.1, C106.1, C107.2, C108.2, C109.2, C110.1, C111.2, C112.1, C113.1, C114.2, C115.1, C116.2, C117.2, C118.1, C119.2, C122.2, C199.2, D3.1 (K), J1.A6 (GND), J1.A7 (GND), J1.A14 (GND), SW1.1, SW1.2, U1.2 (GND), U2.10 (GND), U2.19 (CE), U3.14 (GND), U4.12 (GND), U5.7 (GND), U6.7 (GND), U7.1 (A), U7.6 (Cext), U7.8 (GND), U7.14 (Cext), U8.7 (GND), U9.7 (GND), U13.7 (GND), U14.8 (GND), U15.7 (GND), U16.7 (GND), U19.7 (GND); also elsewhere on the board
unnamed: C5.1, R5.2, U7.15 (RCext)
unnamed: C6.1, R4.2, U7.7 (RCext)
unnamed: D1.1 (K), U5.8
unnamed: D1.2 (A), R6.2, S2.3 (S), U8.13 (~R)
unnamed: D2.1 (K), U5.11
unnamed: D2.2 (A), R7.2, S2.1 (O), U8.10 (~S)
unnamed: D3.2 (A), R8.1
unnamed: D4.2 (A), S2.2
unnamed: D5.1 (K), U9.6
unnamed: D5.2 (A), R9.1
unnamed: JP1.1, U1.3 (OUT)
unnamed: JP2.2, U3.19 (D7)
unnamed: JP2.3, U3.11 (D0)
unnamed: R3.2, S1.3, S1.4 (P1), U7.9 (A)
unnamed: U5.10, U6.8
unnamed: U5.6, U5.9, U5.12
unnamed: U6.6, U8.5 (Q)
unnamed: U7.2 (B), U7.5 (Q)
ROM_A14: R2.1, SW1.4, U3.27 (A14)
ROM_A15: R1.1, SW1.3, U3.1 (A15)
ROM_CE: U3.20 (~CE), U4.22 (IO2)
U10_CP: U4.17 (IO7); also elsewhere on the board
U11_OEB: U4.16 (IO8); also elsewhere on the board
plus3_5V: J1.A3 (+5Vcc), JP1.3

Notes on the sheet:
/ROM_CE = /(BETA_ON + A14 + A15) (no usa + /RD)
ROM_CE = BETA_ON+ A14 + A15 (no usa + /RD)
DIR = /RD + ROM_CE + BETA_ON + /IORQ
noP123 = /(A14+A15)
noP0 = A14 + A15
FDC_CS = /(A0 + A1) + BETA_ON + /IOREQ + /A7
U10_CP = /(A0 + A1) + BETA_ON + /IOREQ + A7 + /RD
U11_OEB = /(A0 + A1) + BETA_ON + /IOREQ + A7 + /WR
/A9 = /A9
IO_WR1= A1+A15+/WR+/IORQ

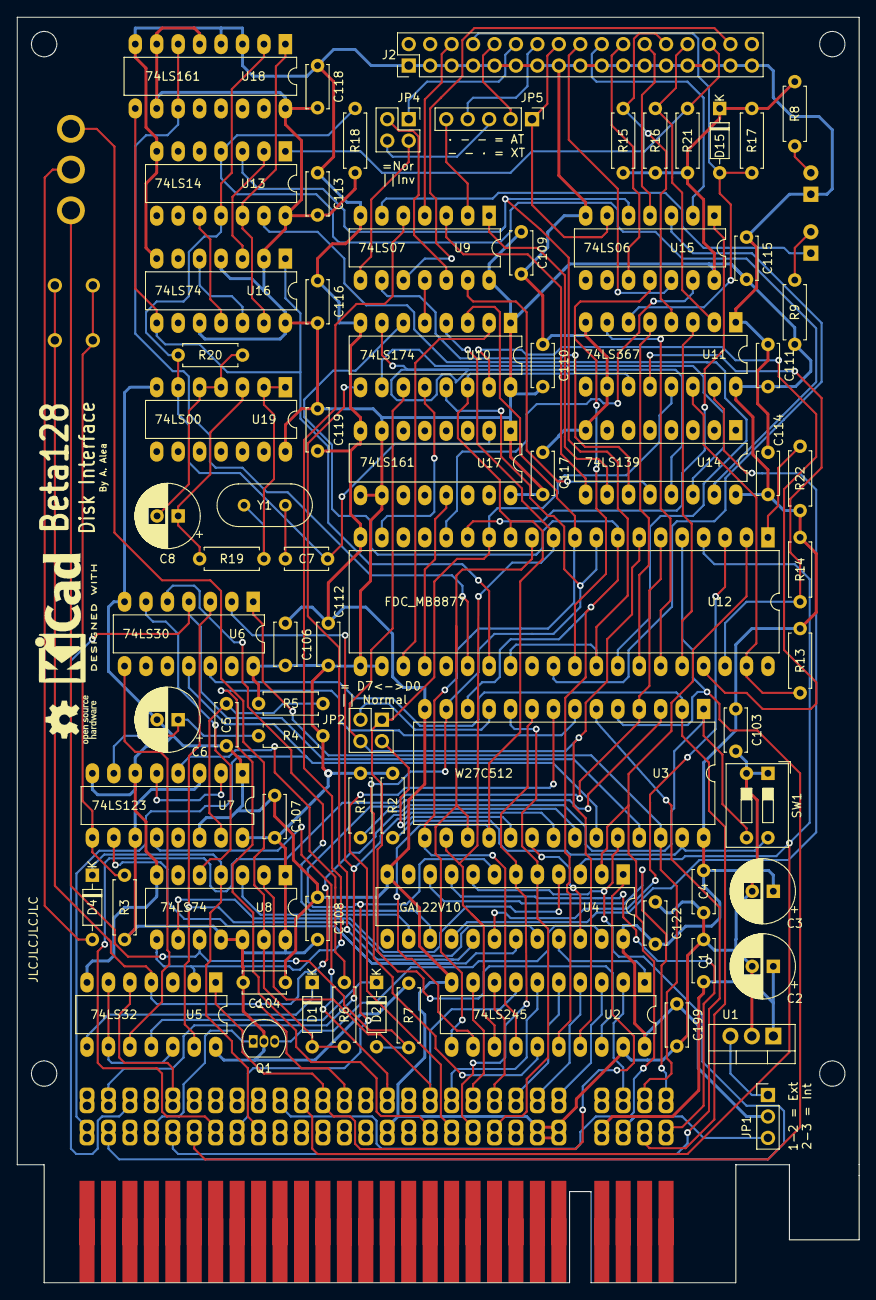
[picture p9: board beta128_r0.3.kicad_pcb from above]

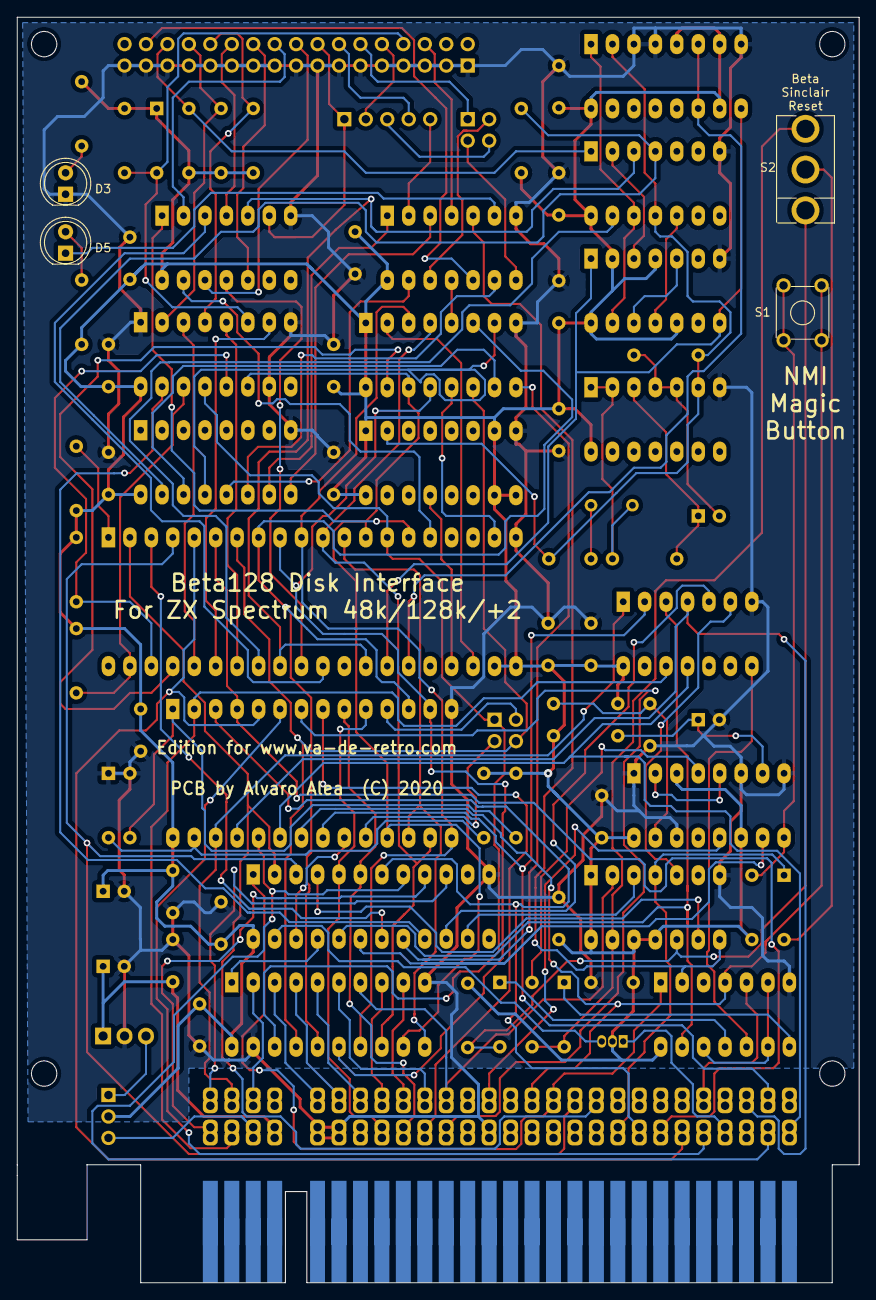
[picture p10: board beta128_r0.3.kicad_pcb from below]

Board: 2 copper layers, 99.7 x 149.9 mm, 89 parts (6 on the bottom side), 130 nets.

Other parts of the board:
REF1: KiCad-Logo2_6mm_SilkScreen
REF2: OSHW-Logo_5.7x6mm_SilkScreen
ZX-EDGE_2, ZX-EDGE_3: ZX_EDGE

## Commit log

2020-03-08 add schematic
2020-03-11 update on libs
    [beta128_r0.3-B_Cu.gbr, beta128_r0.3-B_Mask.gbr, beta128_r0.3-B_SilkS.gbr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]
2020-03-12 schematic in pdf
    [beta128_r0.3.sch]
2020-03-20 update gal code
    [beta128_r0.3.sch]
2020-04-08 add roms to burn
    [beta128_r0.3.sch]
2020-04-08 fix duplicate_label
    [beta128_r0.3-B_Cu.gbr, beta128_r0.3-B_Mask.gbr, beta128_r0.3-B_SilkS.gbr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]
2020-05-08 fix 74ls00 power pins
    [beta128_disk_controler.kicad_sch, beta128_memory_circuit.kicad_sch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]

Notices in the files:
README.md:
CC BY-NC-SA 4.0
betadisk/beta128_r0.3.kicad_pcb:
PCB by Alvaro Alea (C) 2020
